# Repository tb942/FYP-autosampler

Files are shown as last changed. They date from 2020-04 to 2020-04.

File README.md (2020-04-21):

# Thomas Butler's University of Liverpool Final Year Project
## Autosampler
 This repository holds the design files and source code for Thomas Butler's UOL Final Year Project.

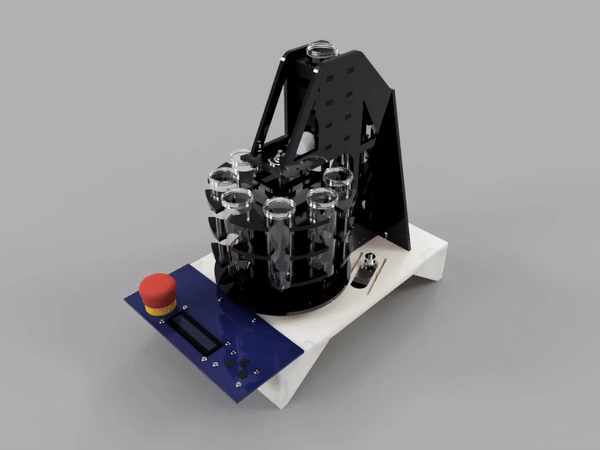
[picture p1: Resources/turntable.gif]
 

### Arduino firmware
The firmware for this project is [Autosampler_firmware.ino](Arduino/Autosampler_firmware/Autosampler_firmware.ino).
To install, place the contents of the [Arduino](Arduino) folder in your Arduino IDE's sketchbook location.

### GUI software
The source files for the Qt creator project are in the [GUI](GUI) folder.

### CAD files
You can get the Fusion 360 assembly file [here](https://a360.co/32DXsge).

### PCB files
The Eagle CAD files and Gerber outputs for the main PCB can be found in the [PCB](PCB) folder.

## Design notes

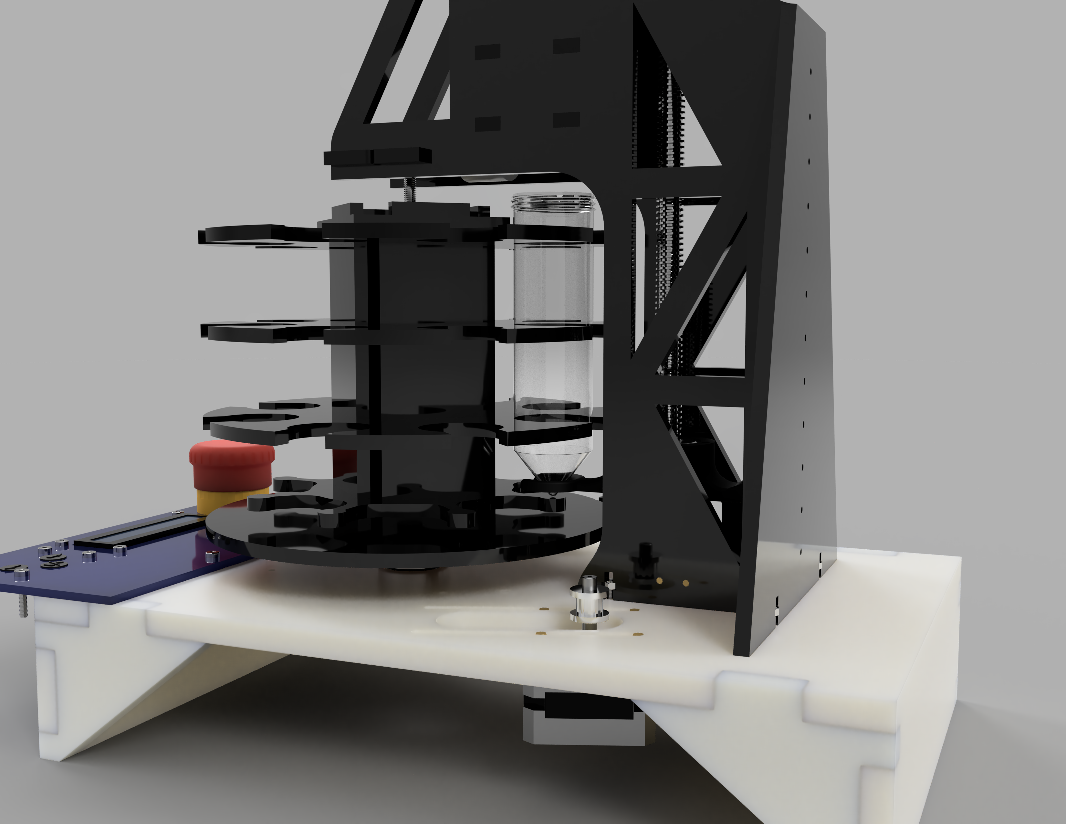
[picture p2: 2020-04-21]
Resources/Side_view.png

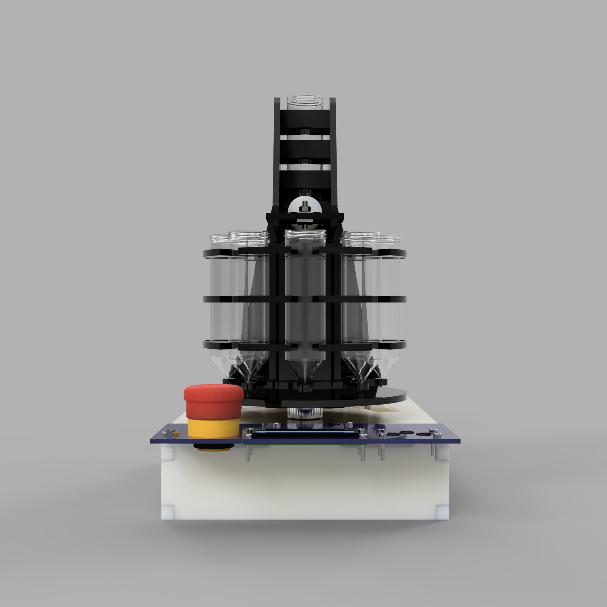
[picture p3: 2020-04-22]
Resources/HQ_render_front.png

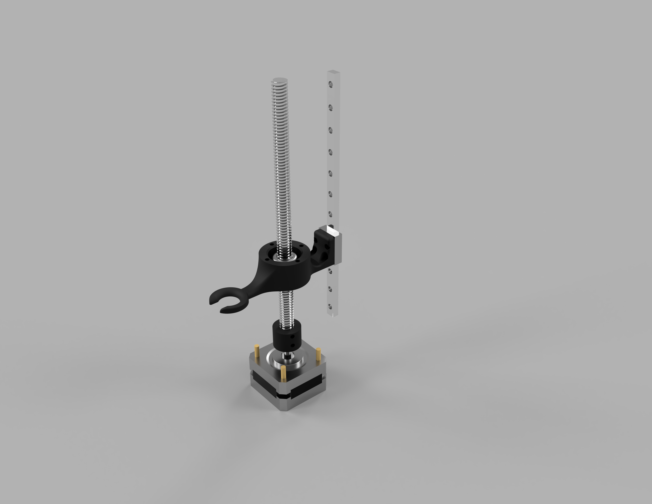
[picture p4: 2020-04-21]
Resources/Lifting_mechanism.png

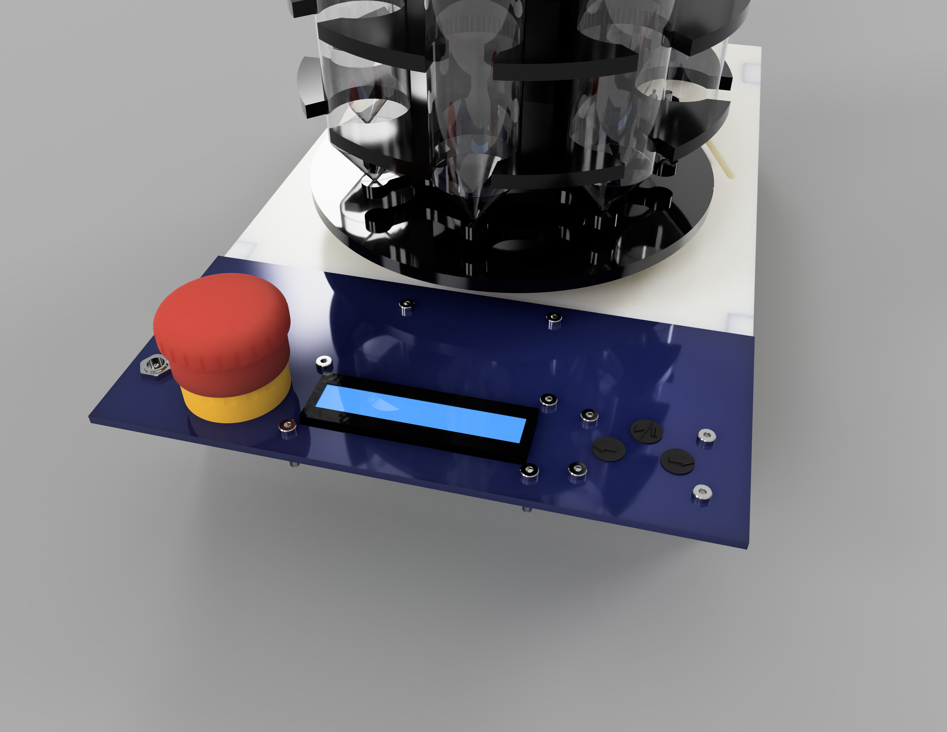
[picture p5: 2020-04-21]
Resources/Control_Panel.png

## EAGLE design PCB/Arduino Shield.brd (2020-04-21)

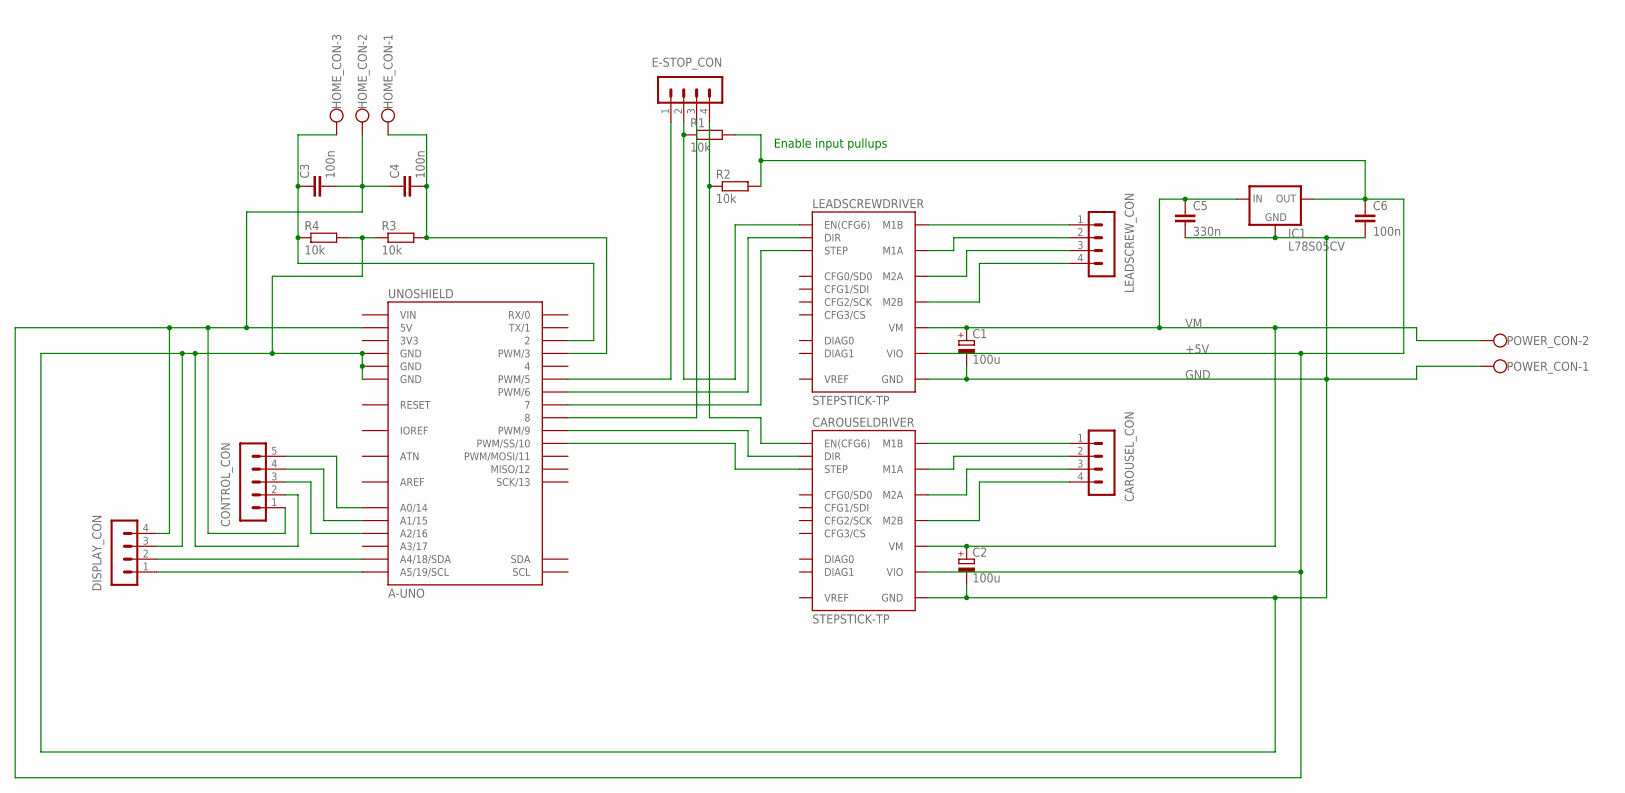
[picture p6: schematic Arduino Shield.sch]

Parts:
C1, C2: 100u; E3,5-8
C3, C4: 100n; C025-024X044
C5: 330n; C025-030X050
C6: 100n; C025-030X050
CAROUSELDRIVER: STEPSTICK-TP; STEPSTICK_TP
CAROUSEL_CON: MA04-1
CONTROL_CON: MA05-1
DISPLAY_CON: MA04-1
E-STOP_CON: MA04-1
HOME_CON: W237-103
IC1: L78S05CV; TO-220-STANDING
LEADSCREWDRIVER: STEPSTICK-TP; STEPSTICK_TP
LEADSCREW_CON: MA04-1
POWER_CON: W237-102
R1, R2: 10k; 0207/12
R3, R4: 10k; 0207/10
UNOSHIELD: A-UNO

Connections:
3V3: UNOSHIELD.3V3
+5V: C3.2, C4.1, C6.1, CAROUSELDRIVER.VIO, CONTROL_CON.1, DISPLAY_CON.4, HOME_CON.2, IC1.3 (OUT), LEADSCREWDRIVER.VIO, R1.2, R2.2, UNOSHIELD.5V
AREF: UNOSHIELD.AREF
GND: C1.-, C2.-, C5.2, C6.2, CAROUSELDRIVER.GND@1 (GND), CAROUSELDRIVER.GND@2 (GND), CONTROL_CON.2, DISPLAY_CON.3, IC1.2 (GND), LEADSCREWDRIVER.GND@1 (GND), LEADSCREWDRIVER.GND@2 (GND), POWER_CON.1, R3.1, R4.2, UNOSHIELD.GND@1 (GND), UNOSHIELD.GND@2 (GND), UNOSHIELD.GND@3 (GND)
IOREF: UNOSHIELD.IOREF
unnamed: E-STOP_CON.2, LEADSCREWDRIVER.EN (EN(CFG6)), R1.1
unnamed: LEADSCREWDRIVER.DIR, UNOSHIELD.6 (PWM/6)
unnamed: LEADSCREWDRIVER.STEP, UNOSHIELD.7
unnamed: CAROUSELDRIVER.EN (EN(CFG6)), E-STOP_CON.4, R2.1
unnamed: CAROUSELDRIVER.DIR, UNOSHIELD.9 (PWM/9)
unnamed: CAROUSELDRIVER.STEP, UNOSHIELD.10 (PWM/SS/10)
unnamed: LEADSCREWDRIVER.M1B, LEADSCREW_CON.1
unnamed: LEADSCREWDRIVER.M1A, LEADSCREW_CON.2
unnamed: LEADSCREWDRIVER.M2B, LEADSCREW_CON.4
unnamed: LEADSCREWDRIVER.M2A, LEADSCREW_CON.3
unnamed: CAROUSELDRIVER.M1B, CAROUSEL_CON.1
unnamed: CAROUSELDRIVER.M1A, CAROUSEL_CON.2
unnamed: CAROUSELDRIVER.M2A, CAROUSEL_CON.3
unnamed: CAROUSELDRIVER.M2B, CAROUSEL_CON.4
unnamed: E-STOP_CON.1, UNOSHIELD.5 (PWM/5)
unnamed: E-STOP_CON.3, UNOSHIELD.8
unnamed: DISPLAY_CON.1, UNOSHIELD.A5 (A5/19/SCL)
unnamed: DISPLAY_CON.2, UNOSHIELD.A4 (A4/18/SDA)
unnamed: C3.1, HOME_CON.3, R4.1, UNOSHIELD.2
unnamed: CONTROL_CON.5, UNOSHIELD.A0 (A0/14)
unnamed: CONTROL_CON.4, UNOSHIELD.A1 (A1/15)
unnamed: CONTROL_CON.3, UNOSHIELD.A2 (A2/16)
unnamed: C4.2, HOME_CON.1, R3.2, UNOSHIELD.3 (PWM/3)
VIN: UNOSHIELD.VIN
VM: C1.+, C2.+, C5.1, CAROUSELDRIVER.VM, IC1.1 (IN), LEADSCREWDRIVER.VM, POWER_CON.2

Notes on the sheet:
Enable input pullups

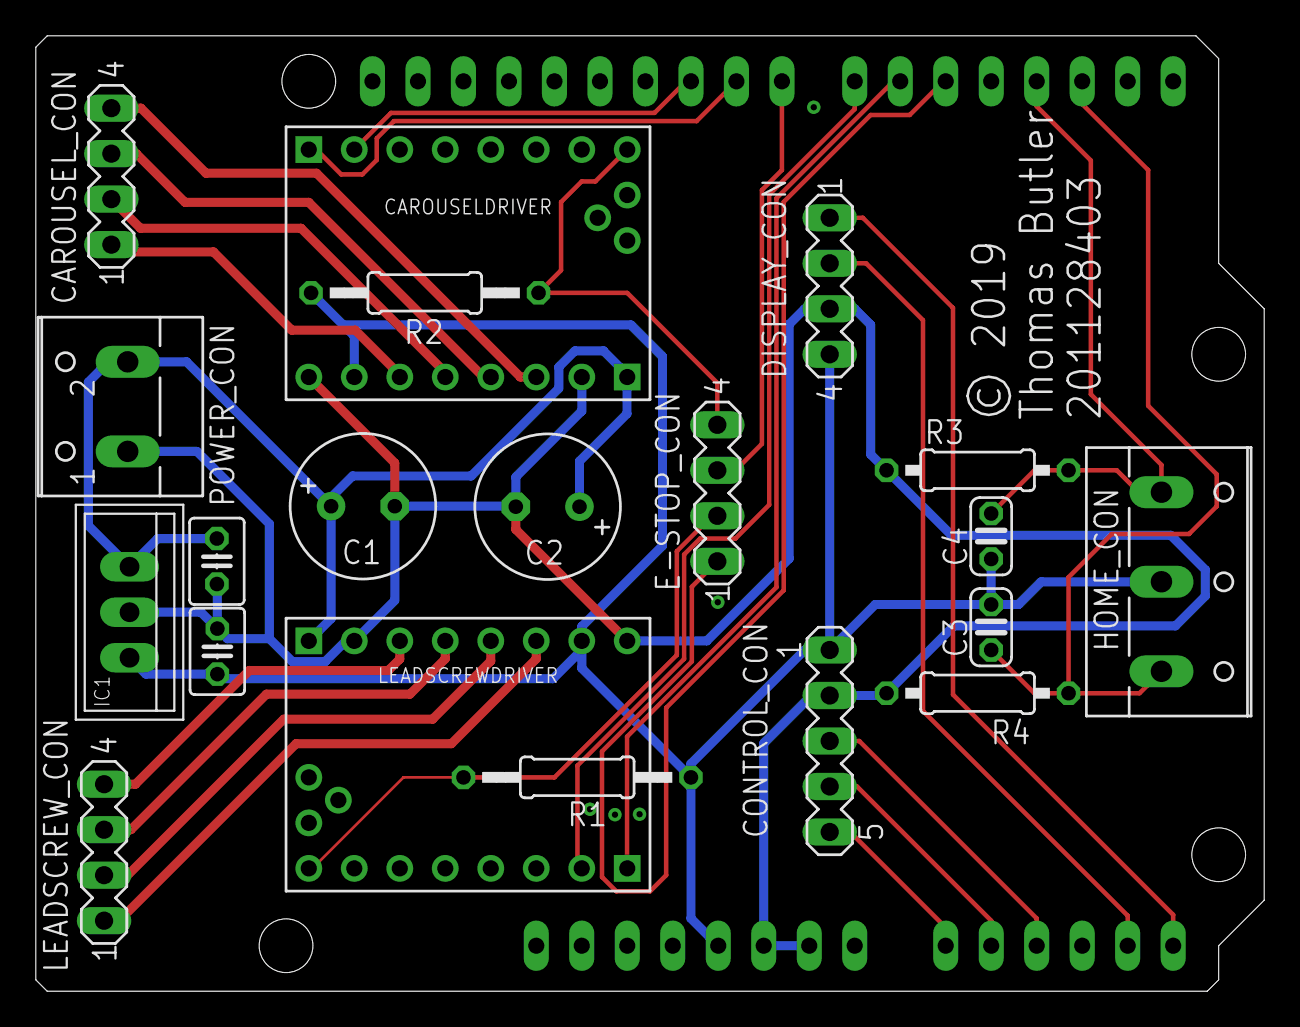
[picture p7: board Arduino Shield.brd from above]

Board: 2 copper layers, 68.6 x 53.3 mm, 21 parts (0 on the bottom side), 26 nets.

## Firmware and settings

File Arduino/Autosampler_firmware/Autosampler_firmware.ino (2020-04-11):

#include <Arduino.h>
#include <Carousel.h>
#include <Commands.h>
#include <LeadScrew.h>
#include <LiquidCrystal_I2C.h>
#include <Wire.h>

// Program Settings
const uint8_t eeprom_sequence_count = 4;
bool extended_serial_messages = true;

// Pin definitions
const uint8_t carousel_step = 10;
const uint8_t carousel_dir = 9;
const uint8_t carousel_ena = 8;
const uint8_t carousel_home = 3;

const uint8_t leadscrew_step = 7;
const uint8_t leadscrew_dir = 6;
const uint8_t leadscrew_ena = 5;
const uint8_t leadscrew_home = 2;

const uint8_t liquid_level_pin = 4;
const uint8_t liquid_sensor_power_pin = 11;
const bool liquid_state = false;
const bool sensor_power_on_state = false;

const uint8_t menu_left = 16;
const uint8_t menu_enter = 15;
const uint8_t menu_right = 14;

uint8_t menu_selection = 1;

// Function declarations
void ConfirmSelection();
void Instructions();
bool IsLeadHomed();
uint8_t CarouselOperate(uint8_t pos);
uint8_t LeadscrewOperate(uint8_t pos);
uint8_t Run(uint8_t program);
uint8_t Write(uint8_t program);
uint8_t Delete(uint8_t program);
uint8_t Sleep(uint8_t value);
uint8_t LiquidLevel(uint8_t pos);
uint8_t MessageMode(uint8_t mode);

// Construction:Mechanism name(DIR, STEP, ENA, HOME);
Carousel carousel(carousel_dir, carousel_step, carousel_ena, carousel_home);
LeadScrew lead(leadscrew_dir, leadscrew_step, leadscrew_ena, leadscrew_home);
LiquidCrystal_I2C lcd(0x27, 2, 1, 0, 4, 5, 6, 7);  // 0x27 is the I2C bus address for an unmodified backpack
Command command;                                   // Holder to read serial buffer into

void setup() {
    carousel.AddInterlock(IsLeadHomed);               // Set leadscrew homed as carousel interlock
    Command::AddCommand('C', CarouselOperate, 1, 8);  // Set commands
    Command::AddCommand('L', LeadscrewOperate, 1, 3);
    Command::AddCommand('V', LiquidLevel, 1, 8);
    Command::AddCommand('R', Run, 1, eeprom_sequence_count);
    Command::AddCommand('W', Write, 1, eeprom_sequence_count);
    Command::AddCommand('D', Delete, 1, eeprom_sequence_count);
    Command::AddCommand('S', Sleep, 1, 99);
    Command::AddCommand('M', MessageMode, 1, 2);
    Command::SetVariables(eeprom_sequence_count, extended_serial_messages);  // Pass compilation settings
    LeadScrew::SetVariables(extended_serial_messages);
    Command::LinkDisplay(lcd);                                               // Pass display control

    Serial.begin(9600);

    pinMode(menu_left, INPUT);  // Initialise pins
    pinMode(menu_enter, INPUT);
    pinMode(menu_right, INPUT);

    pinMode(liquid_level_pin, INPUT);
    pinMode(liquid_sensor_power_pin, OUTPUT);
    digitalWrite(liquid_sensor_power_pin, !sensor_power_on_state);

    lead.begin();      // Initialise lead screw
    carousel.begin();  // Initialise carousel

    // Activate LCD module
    lcd.begin(16, 2);  // As 16 x 2 LCD module
    lcd.setBacklightPin(3, POSITIVE);
    lcd.setBacklight(HIGH);
    lcd.PrintToLcd(F("Autosampler"));  // Splash screen

    lead.home();  // Home lead screw

    if (extended_serial_messages) {
        Serial.print(F("Leadscrew homed\n"));
    }

    lcd.PrintToLcd(F("Leadscrew homed"));

    carousel.home();  // home carousel

    if (extended_serial_messages) {
        Serial.print(F("Carousel homed\n"));
    }

    lcd.PrintToLcd(F("Carousel homed"));

    Instructions();

    Sleep(1);
}

void loop() {
    lcd.PrintToLcd(F("Program"), "Selected: " + String(menu_selection));

    if (Serial.available()) {
        command.GetCommandSerial();  // Read one command
        command.Operate();           // Handle it
    }

    if (digitalRead(menu_enter)) {
        while (digitalRead(menu_enter)) {
        }

        ConfirmSelection();

    } else if (digitalRead(menu_left)) {
        while (digitalRead(menu_left)) {
        }

        menu_selection--;
        if (menu_selection == 0) {
            menu_selection = 4;
        }

    } else if (digitalRead(menu_right)) {
        while (digitalRead(menu_right)) {
        }

        menu_selection++;
        if (menu_selection == 5) {
            menu_selection = 1;
        }
    }
}

void ConfirmSelection() {
    lcd.PrintToLcd(F("Confirm program:"), String(menu_selection) + " Yes(L) / No(R)");
    while (!digitalRead(menu_left) && !digitalRead(menu_right)) {
    }

    if (digitalRead(menu_left)) {
        while (digitalRead(menu_left)) {
        }
        Command program('R', menu_selection);
        program.Operate();
    }
}

void Instructions() {
    if (extended_serial_messages) {
        Serial.print(F("\n\nAutosampler commands format:\n"));
        Serial.print(F("           \"ANN;\"\n\n"));
        Serial.print(F("A = Command, NN = value\n      options:\n\n"));
        Serial.print(F("\"C\"/\"c\" == Carousel\n"));
        Serial.print(F("Valid positions: 1-8\n\n"));
        Serial.print(F("----------OR----------\n\n"));
        Serial.print(F("\"L\"/\"l\" == Leadscrew\n"));
        Serial.print(F("Valid positions: 1-3\n\n"));
        Serial.print(F("----------OR----------\n\n"));
        Serial.print(F("\"V\"/\"v\" == Level Value in tube\n"));
        Serial.print(F("Valid positions: 1-8\n\n"));
        Serial.print(F("----------OR----------\n\n"));
        Serial.print(F("\"S\"/\"s\" == Sleep\n"));
        Serial.print(F("Valid lengths: 1-99\n\n"));
        Serial.print(F("----------OR----------\n\n"));
        Serial.print(F("\"W\"/\"w\" == Write\n"));
        Serial.print(F("Valid lengths: 1-4\n\n"));
        Serial.print(F("----------OR----------\n\n"));
        Serial.print(F("\"R\"/\"r\" == Run\n"));
        Serial.print(F("Valid lengths: 1-4\n\n"));
        Serial.print(F("----------OR----------\n\n"));
        Serial.print(F("\"D\"/\"d\" == Delete\n"));
        Serial.print(F("Valid lengths: 1-4\n\n"));
    }
}

bool IsLeadHomed() { return (lead.is_safe()); }

uint8_t CarouselOperate(uint8_t pos) { return (carousel.operate(pos)); }

uint8_t LeadscrewOperate(uint8_t pos) { return (lead.operate(pos)); }

uint8_t Run(uint8_t program) { return (command.ProgramRun(program)); }

uint8_t Write(uint8_t program) { return (command.ProgramWrite(program)); }

uint8_t Delete(uint8_t program) { return (command.ProgramDelete(program)); }

uint8_t Sleep(uint8_t value) {
    uint8_t pause_flag = 1;
    unsigned long start = millis();

    while (millis() < start + (1000 * (unsigned long)value)) {
        if (digitalRead(14) == HIGH || digitalRead(15) == HIGH || digitalRead(16) == HIGH) {  // flag pause if button pressed
            pause_flag = 2;
        }
    }

    return (pause_flag);
}

uint8_t LiquidLevel(uint8_t pos) {
    if(lead.is_safe()){
      carousel.operate(pos);
    } else {
      lead.operate(1);
      carousel.operate(pos);
    }
    return (lead.LiquidLevel(liquid_sensor_power_pin, liquid_level_pin, liquid_state, sensor_power_on_state, lcd));
}

uint8_t MessageMode(uint8_t mode) {
  if(mode == 2){
    extended_serial_messages = true;
  }
  else {
    extended_serial_messages = false;
  }
  
  Command::SetVariables(eeprom_sequence_count, extended_serial_messages);
  LeadScrew::SetVariables(extended_serial_messages);
  
  return(1);
}

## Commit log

2020-04-11 Removed redundant capacitive sensor library
2020-04-21 Added PCB files
    [Arduino Shield Schematic.sch, Arduino Shield.brd, Arduino Shield.sch]

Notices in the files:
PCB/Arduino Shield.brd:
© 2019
